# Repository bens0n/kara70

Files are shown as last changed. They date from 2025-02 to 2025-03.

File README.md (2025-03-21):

# kara70
70% FRL TKL keyboard assembled with primarily through hole components, including usb type-c. Inspired by cftkb [discipline](https://github.com/coseyfannitutti/discipline) and [mysterium](https://github.com/coseyfannitutti/mysterium), and also envious' [delirium](https://github.com/Envious-Data/Env-KB). 

kara70

kara70

The microcontroller has been updated from an atmega to an RP2040, which is mounted on the back-side to maintain the through-hole look. A slightly unnecessary logic shifter does double duty as a pretend through-hole controller. Underglow RGB has been added, and a minimal (LED diffusing) case connects the base to the plate.

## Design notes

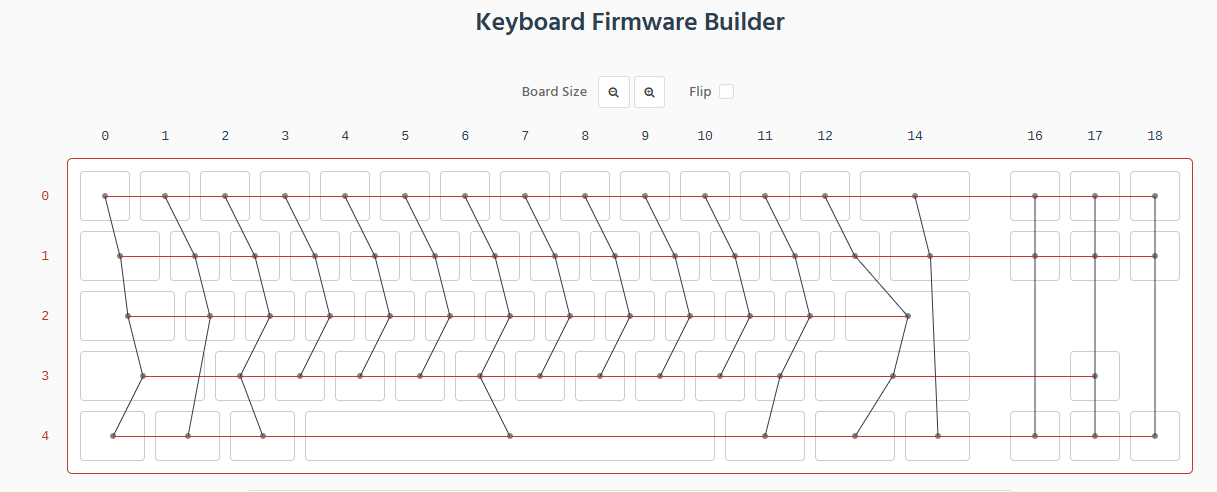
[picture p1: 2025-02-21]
keyboard-matrix.PNG

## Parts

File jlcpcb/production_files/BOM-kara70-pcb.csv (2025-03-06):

Comment | Designator | Footprint | LCSC | Quantity
100nF 0805 | C1,C10,C11,C12,C13,C14,C15,C16,C17,C18,C19,C2,C20,C21,C22,C23,C24,C3,C4,C5,C6,C7,C8,C9 | C_0805_2012Metric_Pad1.18x1.45mm_HandSolder | C28233 | 24
WS2812B | LED1,LED10,LED11,LED12,LED13,LED14,LED15,LED16,LED17,LED18,LED19,LED2,LED20,LED21,LED22,LED23,LED24,LED3,LED4,LED5,LED6,LED7,LED8,LED9 | LED_WS2812B_PLCC4_5.0x5.0mm_P3.2mm | C4154882 | 24
~ | D1 | D_DO-35_SOD27_P5.08mm_Horizontal |  | 1
~ | D2 | D_DO-35_SOD27_P5.08mm_Horizontal |  | 1
~ | D3 | D_DO-35_SOD27_P5.08mm_Horizontal |  | 1
~ | D4 | D_DO-35_SOD27_P5.08mm_Horizontal |  | 1
~ | D5 | D_DO-35_SOD27_P5.08mm_Horizontal |  | 1
~ | D6 | D_DO-35_SOD27_P5.08mm_Horizontal |  | 1
~ | D7 | D_DO-35_SOD27_P5.08mm_Horizontal |  | 1
~ | D8 | D_DO-35_SOD27_P5.08mm_Horizontal |  | 1
~ | D9 | D_DO-35_SOD27_P5.08mm_Horizontal |  | 1
~ | D10 | D_DO-35_SOD27_P5.08mm_Horizontal |  | 1
~ | D11 | D_DO-35_SOD27_P5.08mm_Horizontal |  | 1
~ | D12 | D_DO-35_SOD27_P5.08mm_Horizontal |  | 1
~ | D13 | D_DO-35_SOD27_P5.08mm_Horizontal |  | 1
~ | D14 | D_DO-35_SOD27_P5.08mm_Horizontal |  | 1
~ | D16 | D_DO-35_SOD27_P5.08mm_Horizontal |  | 1
~ | D17 | D_DO-35_SOD27_P5.08mm_Horizontal |  | 1
~ | D18 | D_DO-35_SOD27_P5.08mm_Horizontal |  | 1
~ | D19 | D_DO-35_SOD27_P5.08mm_Horizontal |  | 1
~ | D20 | D_DO-35_SOD27_P5.08mm_Horizontal |  | 1
~ | D21 | D_DO-35_SOD27_P5.08mm_Horizontal |  | 1
~ | D22 | D_DO-35_SOD27_P5.08mm_Horizontal |  | 1
~ | D23 | D_DO-35_SOD27_P5.08mm_Horizontal |  | 1
~ | D24 | D_DO-35_SOD27_P5.08mm_Horizontal |  | 1
~ | D25 | D_DO-35_SOD27_P5.08mm_Horizontal |  | 1
~ | D26 | D_DO-35_SOD27_P5.08mm_Horizontal |  | 1
~ | D27 | D_DO-35_SOD27_P5.08mm_Horizontal |  | 1
~ | D28 | D_DO-35_SOD27_P5.08mm_Horizontal |  | 1
~ | D29 | D_DO-35_SOD27_P5.08mm_Horizontal |  | 1
~ | D31 | D_DO-35_SOD27_P5.08mm_Horizontal |  | 1
~ | D32 | D_DO-35_SOD27_P5.08mm_Horizontal |  | 1
~ | D33 | D_DO-35_SOD27_P5.08mm_Horizontal |  | 1
~ | D34 | D_DO-35_SOD27_P5.08mm_Horizontal |  | 1
~ | D35 | D_DO-35_SOD27_P5.08mm_Horizontal |  | 1
~ | D36 | D_DO-35_SOD27_P5.08mm_Horizontal |  | 1
~ | D37 | D_DO-35_SOD27_P5.08mm_Horizontal |  | 1
~ | D38 | D_DO-35_SOD27_P5.08mm_Horizontal |  | 1
~ | D39 | D_DO-35_SOD27_P5.08mm_Horizontal |  | 1
~ | D40 | D_DO-35_SOD27_P5.08mm_Horizontal |  | 1
~ | D41 | D_DO-35_SOD27_P5.08mm_Horizontal |  | 1
~ | D42 | D_DO-35_SOD27_P5.08mm_Horizontal |  | 1
~ | D43 | D_DO-35_SOD27_P5.08mm_Horizontal |  | 1
~ | D45 | D_DO-35_SOD27_P5.08mm_Horizontal |  | 1
~ | D46 | D_DO-35_SOD27_P5.08mm_Horizontal |  | 1
~ | D47 | D_DO-35_SOD27_P5.08mm_Horizontal |  | 1
~ | D48 | D_DO-35_SOD27_P5.08mm_Horizontal |  | 1
~ | D49 | D_DO-35_SOD27_P5.08mm_Horizontal |  | 1
~ | D50 | D_DO-35_SOD27_P5.08mm_Horizontal |  | 1
~ | D51 | D_DO-35_SOD27_P5.08mm_Horizontal |  | 1
~ | D52 | D_DO-35_SOD27_P5.08mm_Horizontal |  | 1
~ | D53 | D_DO-35_SOD27_P5.08mm_Horizontal |  | 1
~ | D54 | D_DO-35_SOD27_P5.08mm_Horizontal |  | 1
~ | D55 | D_DO-35_SOD27_P5.08mm_Horizontal |  | 1
~ | D56 | D_DO-35_SOD27_P5.08mm_Horizontal |  | 1
~ | D59 | D_DO-35_SOD27_P5.08mm_Horizontal |  | 1
~ | D60 | D_DO-35_SOD27_P5.08mm_Horizontal |  | 1
~ | D61 | D_DO-35_SOD27_P5.08mm_Horizontal |  | 1
~ | D62 | D_DO-35_SOD27_P5.08mm_Horizontal |  | 1
~ | D73 | D_DO-35_SOD27_P5.08mm_Horizontal |  | 1
~ | D74 | D_DO-35_SOD27_P5.08mm_Horizontal |  | 1
~ | D79 | D_DO-35_SOD27_P5.08mm_Horizontal |  | 1
SN74AHCT125N | U1 | N14 |  | 1
~ | D75 | D_DO-35_SOD27_P5.08mm_Horizontal |  | 1
3.6V | D70 | D_DO-35_SOD27_P5.08mm_Horizontal |  | 1
USB_C_GCT_USB4085 | USB1 | USB_C_GCT_USB4085 |  | 1
5.1k | R2 | R_Axial_DIN0204_L3.6mm_D1.6mm_P7.62mm_Horizontal |  | 1
~ | D81 | D_DO-35_SOD27_P5.08mm_Horizontal |  | 1
~ | D83 | D_DO-35_SOD27_P5.08mm_Horizontal |  | 1
~ | D57 | D_DO-35_SOD27_P5.08mm_Horizontal |  | 1
~ | D82 | D_DO-35_SOD27_P5.08mm_Horizontal |  | 1
5.1k | R1 | R_Axial_DIN0204_L3.6mm_D1.6mm_P7.62mm_Horizontal |  | 1
~ | D76 | D_DO-35_SOD27_P5.08mm_Horizontal |  | 1
~ | D77 | D_DO-35_SOD27_P5.08mm_Horizontal |  | 1
500mA | F1 | polyfuse_5.1mm |  | 1
~ | D72 | D_DO-35_SOD27_P5.08mm_Horizontal |  | 1
3.6V | D69 | D_DO-35_SOD27_P5.08mm_Horizontal |  | 1
~ | D78 | D_DO-35_SOD27_P5.08mm_Horizontal |  | 1
~ | D80 | D_DO-35_SOD27_P5.08mm_Horizontal |  | 1
KEYSW | SW1 | MX-Hotswap-1U |  | 1
KEYSW | SW2 | MX-Hotswap-1U |  | 1
KEYSW | SW3 | MX-Hotswap-1U |  | 1
KEYSW | SW4 | MX-Hotswap-1U |  | 1
KEYSW | SW5 | MX-Hotswap-1U |  | 1
KEYSW | SW6 | MX-Hotswap-1U |  | 1
KEYSW | SW7 | MX-Hotswap-1U |  | 1
KEYSW | SW8 | MX-Hotswap-1U |  | 1
KEYSW | SW9 | MX-Hotswap-1U |  | 1
KEYSW | SW10 | MX-Hotswap-1U |  | 1
KEYSW | SW11 | MX-Hotswap-1U |  | 1
KEYSW | SW12 | MX-Hotswap-1U |  | 1
KEYSW | SW13 | MX-Hotswap-1U |  | 1
KEYSW | SW17 | MX-Hotswap-1U |  | 1
KEYSW | SW18 | MX-Hotswap-1U |  | 1
KEYSW | SW19 | MX-Hotswap-1U |  | 1
KEYSW | SW20 | MX-Hotswap-1U |  | 1
KEYSW | SW21 | MX-Hotswap-1U |  | 1
KEYSW | SW22 | MX-Hotswap-1U |  | 1
KEYSW | SW23 | MX-Hotswap-1U |  | 1
KEYSW | SW24 | MX-Hotswap-1U |  | 1
KEYSW | SW25 | MX-Hotswap-1U |  | 1
KEYSW | SW26 | MX-Hotswap-1U |  | 1
KEYSW | SW27 | MX-Hotswap-1U |  | 1
KEYSW | SW28 | MX-Hotswap-1U |  | 1
KEYSW | SW32 | MX-Hotswap-1U |  | 1
KEYSW | SW33 | MX-Hotswap-1U |  | 1
KEYSW | SW34 | MX-Hotswap-1U |  | 1
KEYSW | SW35 | MX-Hotswap-1U |  | 1
KEYSW | SW36 | MX-Hotswap-1U |  | 1
KEYSW | SW37 | MX-Hotswap-1U |  | 1
KEYSW | SW38 | MX-Hotswap-1U |  | 1
KEYSW | SW39 | MX-Hotswap-1U |  | 1
KEYSW | SW40 | MX-Hotswap-1U |  | 1
KEYSW | SW41 | MX-Hotswap-1U |  | 1
KEYSW | SW42 | MX-Hotswap-1U |  | 1
KEYSW | SW46 | MX-Hotswap-1U |  | 1
KEYSW | SW47 | MX-Hotswap-1U |  | 1
KEYSW | SW48 | MX-Hotswap-1U |  | 1
KEYSW | SW49 | MX-Hotswap-1U |  | 1
KEYSW | SW50 | MX-Hotswap-1U |  | 1
KEYSW | SW51 | MX-Hotswap-1U |  | 1
KEYSW | SW52 | MX-Hotswap-1U |  | 1
KEYSW | SW53 | MX-Hotswap-1U |  | 1
KEYSW | SW54 | MX-Hotswap-1U |  | 1
KEYSW | SW55 | MX-Hotswap-1U |  | 1
KEYSW | SW62 | MX-Hotswap-7U-ReversedStabilizers |  | 1
KEYSW | SW14 | MX-Hotswap-2U |  | 1
KEYSW | SW29 | MX-Hotswap-1.5U |  | 1
KEYSW | SW31 | MX-Hotswap-1.75U |  | 1
KEYSW | SW43 | MX-Hotswap-2.25U |  | 1
KEYSW | SW45 | MX-Hotswap-2.25U |  | 1
KEYSW | SW56 | MX-Hotswap-2.75U |  | 1
KEYSW | SW59 | MX-Hotswap-1.25U |  | 1
KEYSW | SW60 | MX-Hotswap-1.25U |  | 1
KEYSW | SW61 | MX-Hotswap-1.25U |  | 1
KEYSW | SW73 | MX-Hotswap-1.5U |  | 1
KEYSW | SW74 | MX-Hotswap-1.5U |  | 1
KEYSW | SW16 | MX-Hotswap-1.5U |  | 1
KEYSW | SW82 | MX-Hotswap-1U |  | 1
KEYSW | SW80 | MX-Hotswap-1U |  | 1
KEYSW | SW83 | MX-Hotswap-1U |  | 1
KEYSW | SW81 | MX-Hotswap-1U |  | 1
KEYSW | SW76 | MX-Hotswap-1U |  | 1
KEYSW | SW72 | MX-Hotswap-1U |  | 1
KEYSW | SW79 | MX-Hotswap-1U |  | 1
KEYSW | SW77 | MX-Hotswap-1U |  | 1
KEYSW | SW57 | MX-Hotswap-1.25U |  | 1
KEYSW | SW78 | MX-Hotswap-1U |  | 1
KEYSW | SW75 | MX-Hotswap-1U |  | 1
RP2040_Stamp | U2 | RP2xxx_Stamp_SMD |  | 1

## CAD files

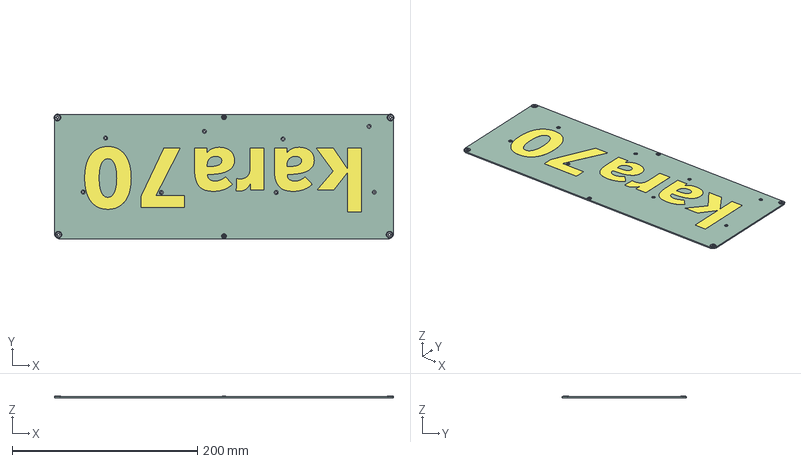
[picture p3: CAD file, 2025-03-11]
base/base.step
366.8 x 134.6 x 2.14 mm
STP_9774005360_rev1 x 4
STP_9774005243_rev1 x 2
base_copper
base_pad
base_PCB

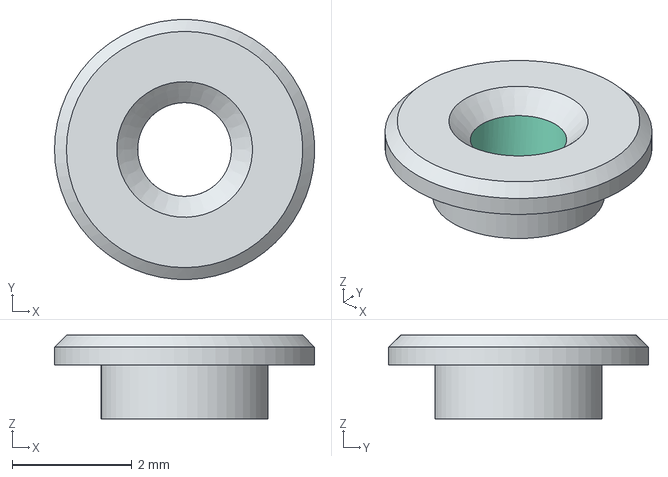
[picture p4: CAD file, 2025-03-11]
discipline-lib/3d/STP_9774005243_rev1.stp
4.35 x 4.35 x 1.40 mm

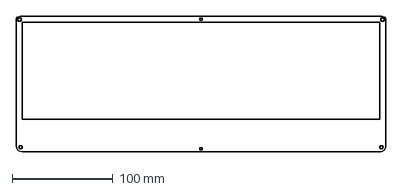
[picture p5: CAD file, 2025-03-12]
laser_cutting/acrylic_top_plate.dxf
366.2 x 134.3 mm

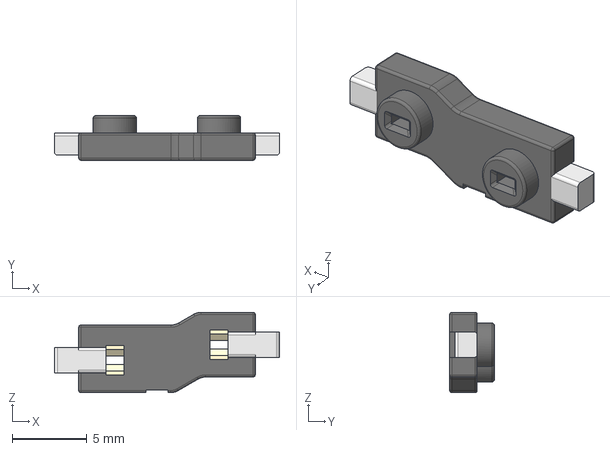
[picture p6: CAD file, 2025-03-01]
MX_V2/3D/Gateron-KS33-Socket.step
15.1 x 3.00 x 5.40 mm

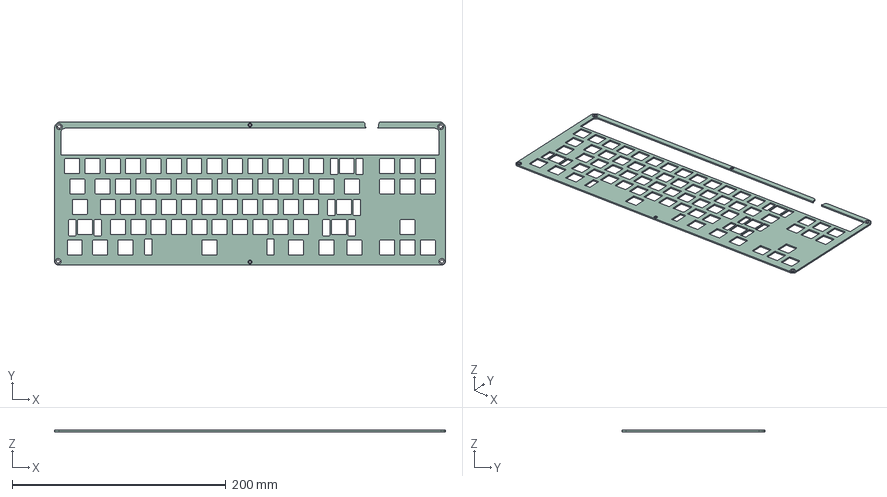
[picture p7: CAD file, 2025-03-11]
plate/plate.step
366.2 x 134.3 x 1.59 mm
plate_pad
plate_PCB

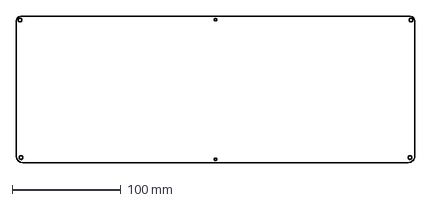
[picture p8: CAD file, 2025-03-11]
base/base-outline.dxf
366.2 x 134.3 mm

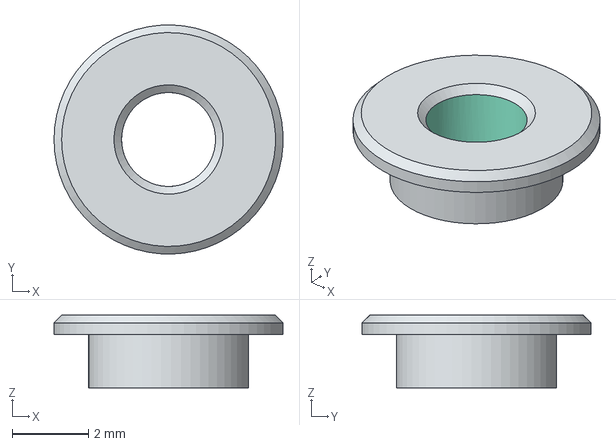
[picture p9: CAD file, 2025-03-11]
discipline-lib/3d/STP_9774005360_rev1.stp
6.00 x 6.00 x 1.90 mm

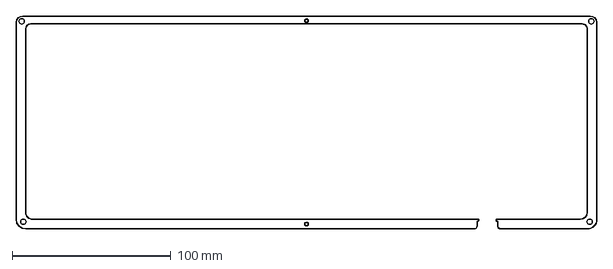
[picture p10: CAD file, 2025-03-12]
laser_cutting/diffuser_with_cutout.dxf
366.2 x 134.3 mm

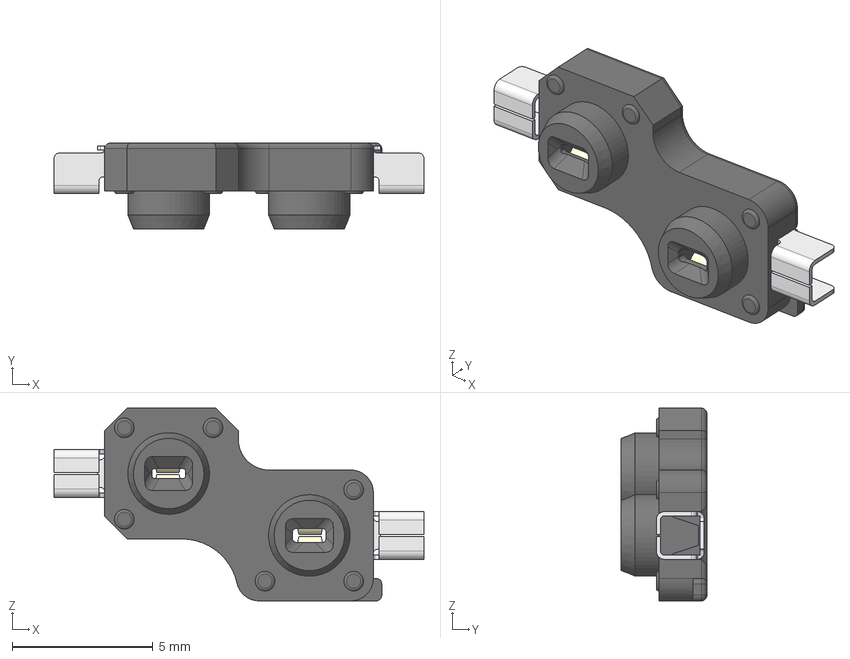
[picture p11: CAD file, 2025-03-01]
MX_V2/3D/Kailh-Choc-Socket-CPG135001S30.step
13.1 x 3.05 x 6.85 mm
Insert 2
Insert 1

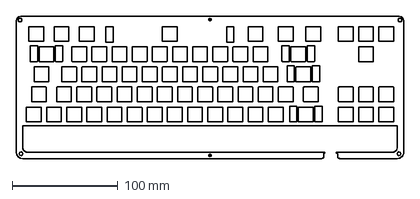
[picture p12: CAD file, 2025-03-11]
plate/plate-outline.dxf
366.2 x 134.3 mm

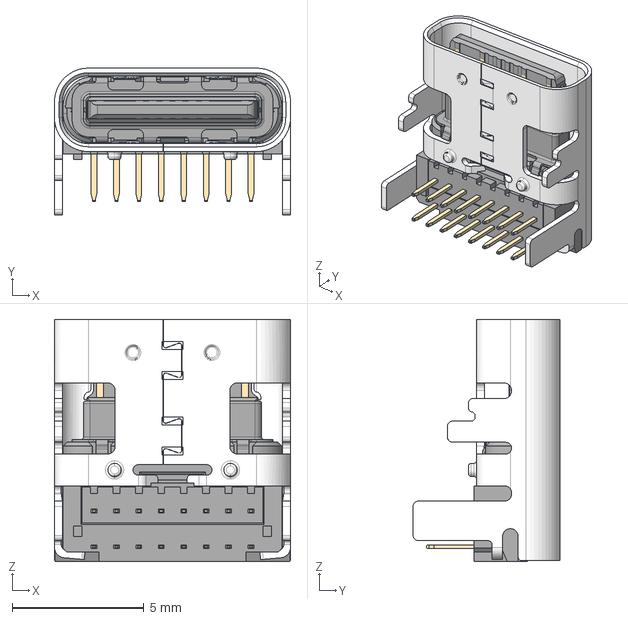
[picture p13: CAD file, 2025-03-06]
discipline-lib/3d/usb4085-gf-a.stp
8.94 x 5.56 x 9.17 mm

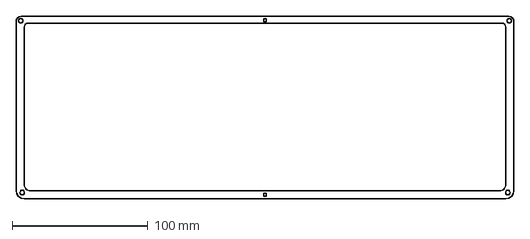
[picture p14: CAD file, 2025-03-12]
laser_cutting/diffuser_no_cutout.dxf
366.2 x 134.3 mm

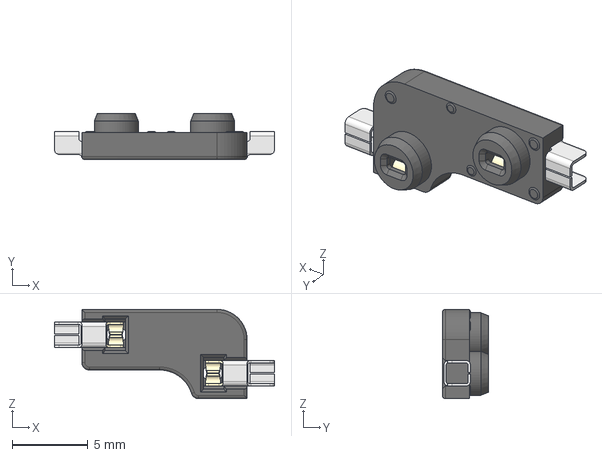
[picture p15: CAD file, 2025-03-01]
MX_V2/3D/MX-Hotswap-Socket.step
14.5 x 3.05 x 5.89 mm

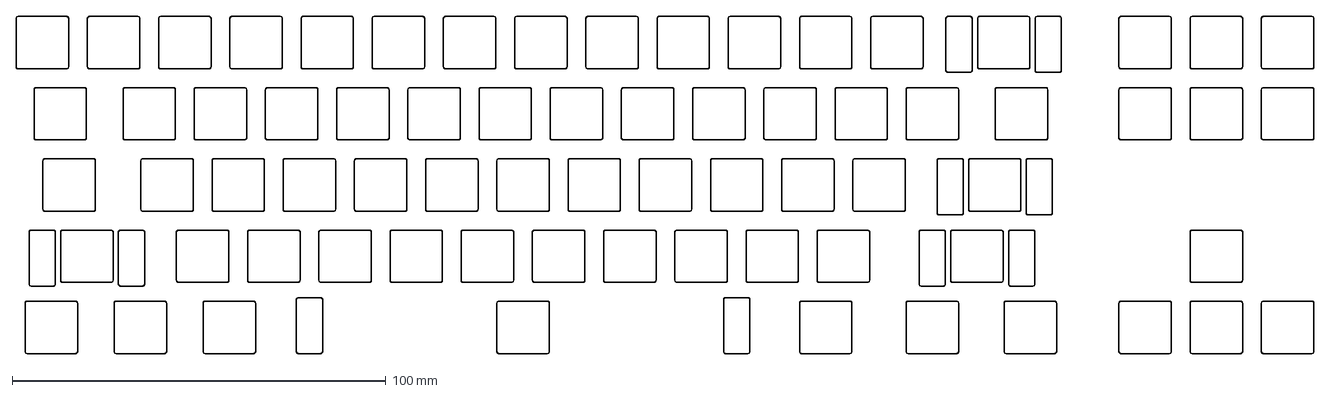
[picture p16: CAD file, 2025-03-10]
plate/keebio_plate_gen.dxf
347.1 x 90.2 mm

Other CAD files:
plate/pcb_outline.dxf
plate/ai03_plate_gen.dxf
discipline-lib/3d/usb4085-gf-a.stl

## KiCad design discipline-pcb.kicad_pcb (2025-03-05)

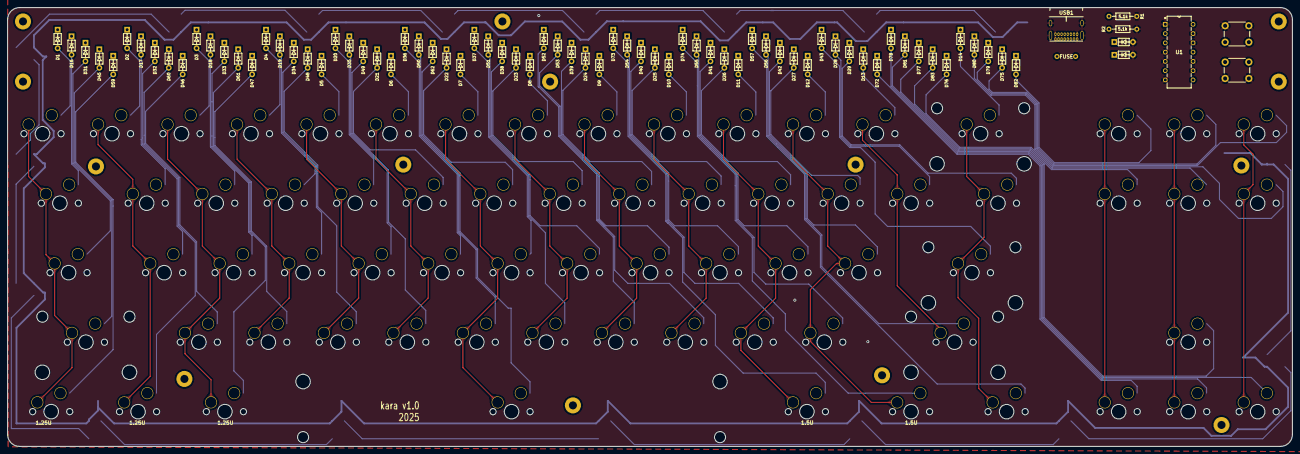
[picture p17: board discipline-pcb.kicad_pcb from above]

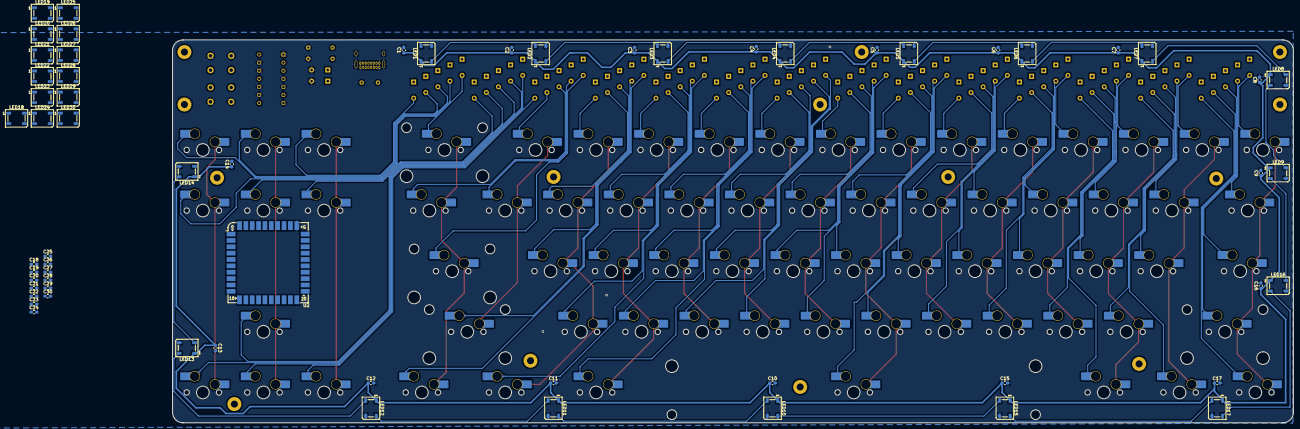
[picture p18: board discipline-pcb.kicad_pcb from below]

Board: 2 copper layers, 352.2 x 120.3 mm, 210 parts (131 on the bottom side), 132 nets.

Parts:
C1, C2, C3, C4, C5, C6, C7, C8, C9, C10, C11, C12, C13, C14, C15, C16, C17, C18, C19, C20, C21, C22, C23, C24, C25, C26, C27, C28, C29, C30: 100nF 0603; C_0603_1608Metric_Pad1.08x0.95mm_HandSolder
D1, D2, D3, D4, D5, D6, D7, D8, D9, D10, D11, D12, D13, D14, D16, D17, D18, D19, D20, D21, D22, D23, D24, D25, D26, D27, D28, D29, D31, D32, D33, D34, D35, D36, D37, D38, D39, D40, D41, D42, D43, D45, D46, D47, D48, D49, D50, D51, D52, D53, D54, D55, D56, D57, D59, D60, D61, D62, D72, D73, D74, D75, D76, D77, D78, D79, D80, D81, D82, D83: D_DO-35_SOD27_P5.08mm_Horizontal
D69, D70: 3.6V; D_DO-35_SOD27_P5.08mm_Horizontal
F1: 500mA; polyfuse_5.1mm
LED1, LED2, LED3, LED4, LED5, LED6, LED7, LED8, LED9, LED10, LED11, LED12, LED13, LED14, LED15, LED16, LED17, LED18, LED19, LED20, LED21, LED22, LED23, LED24, LED25, LED26, LED27, LED28, LED29, LED30: WS2812B; LED_WS2812B_PLCC4_5.0x5.0mm_P3.2mm
R1, R2: 5.1k; R_Axial_DIN0204_L3.6mm_D1.6mm_P7.62mm_Horizontal
SW1, SW2, SW3, SW4, SW5, SW6, SW7, SW8, SW9, SW10, SW11, SW12, SW13, SW17, SW18, SW19, SW20, SW21, SW22, SW23, SW24, SW25, SW26, SW27, SW28, SW32, SW33, SW34, SW35, SW36, SW37, SW38, SW39, SW40, SW41, SW42, SW46, SW47, SW48, SW49, SW50, SW51, SW52, SW53, SW54, SW55, SW72, SW75, SW76, SW77, SW78, SW79, SW80, SW81, SW82, SW83: KEYSW; MX-Hotswap-1U
SW14: KEYSW; MX-Hotswap-2U
SW16, SW29, SW73, SW74: KEYSW; MX-Hotswap-1.5U
SW31: KEYSW; MX-Hotswap-1.75U
SW43, SW45: KEYSW; MX-Hotswap-2.25U
SW56: KEYSW; MX-Hotswap-2.75U
SW57, SW59, SW60, SW61: KEYSW; MX-Hotswap-1.25U
SW62: KEYSW; MX-Hotswap-7U-ReversedStabilizers
SW-RST1, SW-RST2: SW_PUSH_6mm
U1: SN74AHCT125N; N14
U2: RP2040_Stamp; RP2xxx_Stamp_SMD
USB1: USB_C_GCT_USB4085

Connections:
+5V: C1.1, C2.1, C3.1, C4.1, C5.1, C6.1, C7.1, C8.1, C9.1, C10.1, C11.1, C12.1, C13.1, C14.1, C15.1, C16.1, C17.1, C18.1, C19.1, C20.1, C21.1, C22.1, C23.1, C24.1, C25.1, C26.1, C27.1, C28.1, C29.1, C30.1, F1.1, LED1.1 (VDD), LED2.1 (VDD), LED3.1 (VDD), LED4.1 (VDD), LED5.1 (VDD), LED6.1 (VDD), LED7.1 (VDD), LED8.1 (VDD), LED9.1 (VDD), LED10.1 (VDD), LED11.1 (VDD), LED12.1 (VDD), LED13.1 (VDD), LED14.1 (VDD), LED15.1 (VDD), LED16.1 (VDD), LED17.1 (VDD), LED18.1 (VDD), LED19.1 (VDD), LED20.1 (VDD), LED21.1 (VDD), LED22.1 (VDD), LED23.1 (VDD), LED24.1 (VDD), LED25.1 (VDD), LED26.1 (VDD), LED27.1 (VDD), LED28.1 (VDD), LED29.1 (VDD), LED30.1 (VDD), U1.14 (VCC), U2.33 (5V)
Bootselbtn: SW-RST2.1, U2.40 (BOOTSEL)
D+: D70.1 (K), U2.36 (USB_D+), USB1.A6 (DP1), USB1.B6 (DP2)
D-: D69.1 (K), U2.35 (USB_D-), USB1.A7 (DN1), USB1.B7 (DN2)
GND: C1.2, C2.2, C3.2, C4.2, C5.2, C6.2, C7.2, C8.2, C9.2, C10.2, C11.2, C12.2, C13.2, C14.2, C15.2, C16.2, C17.2, C18.2, C19.2, C20.2, C21.2, C22.2, C23.2, C24.2, C25.2, C26.2, C27.2, C28.2, C29.2, C30.2, D69.2 (A), D70.2 (A), LED1.3 (VSS), LED2.3 (VSS), LED3.3 (VSS), LED4.3 (VSS), LED5.3 (VSS), LED6.3 (VSS), LED7.3 (VSS), LED8.3 (VSS), LED9.3 (VSS), LED10.3 (VSS), LED11.3 (VSS), LED12.3 (VSS), LED13.3 (VSS), LED14.3 (VSS), LED15.3 (VSS), LED16.3 (VSS), LED17.3 (VSS), LED18.3 (VSS), LED19.3 (VSS), LED20.3 (VSS), LED21.3 (VSS), LED22.3 (VSS), LED23.3 (VSS), LED24.3 (VSS), LED25.3 (VSS), LED26.3 (VSS), LED27.3 (VSS), LED28.3 (VSS), LED29.3 (VSS), LED30.3 (VSS), R1.1, R2.2, SW-RST1.2, SW-RST2.2, U1.1 (*1OE), U1.4 (*2OE), U1.5 (2A), U1.7 (GND), U1.9 (3A), U1.10 (*3OE), U1.12 (4A), U1.13 (*4OE), U2.31 (GND), USB1.A1 (GND), USB1.A12 (GND), USB1.B1 (GND), USB1.B12 (GND), USB1.S1 (SHIELD)
unnamed: D1.2 (A), SW1.2
unnamed: D2.2 (A), SW2.2
unnamed: D3.2 (A), SW3.2
unnamed: D4.2 (A), SW4.2
unnamed: D5.2 (A), SW5.2
unnamed: D6.2 (A), SW6.2
unnamed: D7.2 (A), SW7.2
unnamed: D8.2 (A), SW8.2
unnamed: D9.2 (A), SW9.2
unnamed: D10.2 (A), SW10.2
unnamed: D11.2 (A), SW11.2
unnamed: D12.2 (A), SW12.2
unnamed: D13.2 (A), SW13.2
unnamed: D14.2 (A), SW14.2
unnamed: D16.2 (A), SW16.2
unnamed: D17.2 (A), SW17.2
unnamed: D18.2 (A), SW18.2
unnamed: D19.2 (A), SW19.2
unnamed: D20.2 (A), SW20.2
unnamed: D21.2 (A), SW21.2
unnamed: D22.2 (A), SW22.2
unnamed: D23.2 (A), SW23.2
unnamed: D24.2 (A), SW24.2
unnamed: D25.2 (A), SW25.2
unnamed: D26.2 (A), SW26.2
unnamed: D27.2 (A), SW27.2
unnamed: D28.2 (A), SW28.2
unnamed: D29.2 (A), SW29.2
unnamed: D31.2 (A), SW31.2
unnamed: D32.2 (A), SW32.2
unnamed: D33.2 (A), SW33.2
unnamed: D34.2 (A), SW34.2
unnamed: D35.2 (A), SW35.2
unnamed: D36.2 (A), SW36.2
unnamed: D37.2 (A), SW37.2
unnamed: D38.2 (A), SW38.2
unnamed: D39.2 (A), SW39.2
unnamed: D40.2 (A), SW40.2
unnamed: D41.2 (A), SW41.2
unnamed: D42.2 (A), SW42.2
unnamed: D43.2 (A), SW43.2
unnamed: D45.2 (A), SW45.2
unnamed: D46.2 (A), SW46.2
unnamed: D47.2 (A), SW47.2
unnamed: D48.2 (A), SW48.2
unnamed: D49.2 (A), SW49.2
unnamed: D50.2 (A), SW50.2
unnamed: D51.2 (A), SW51.2
unnamed: D52.2 (A), SW52.2
unnamed: D53.2 (A), SW53.2
unnamed: D54.2 (A), SW54.2
unnamed: D55.2 (A), SW55.2
unnamed: D56.2 (A), SW56.2
unnamed: D57.2 (A), SW57.2
unnamed: D59.2 (A), SW59.2
unnamed: D60.2 (A), SW60.2
unnamed: D61.2 (A), SW61.2
unnamed: D62.2 (A), SW62.2
unnamed: D72.2 (A), SW72.2
unnamed: D73.2 (A), SW73.2
unnamed: D74.2 (A), SW74.2
unnamed: D75.2 (A), SW75.2
unnamed: D76.2 (A), SW76.2
unnamed: D77.2 (A), SW77.2
unnamed: D78.2 (A), SW78.2
unnamed: D79.2 (A), SW79.2
unnamed: D80.2 (A), SW80.2
unnamed: D81.2 (A), SW81.2
unnamed: D82.2 (A), SW82.2
unnamed: D83.2 (A), SW83.2
unnamed: LED1.2 (DOUT), LED2.4 (DIN)
unnamed: LED2.2 (DOUT), LED3.4 (DIN)
unnamed: LED3.2 (DOUT), LED4.4 (DIN)
unnamed: LED4.2 (DOUT), LED5.4 (DIN)
unnamed: LED5.2 (DOUT), LED6.4 (DIN)
unnamed: LED6.2 (DOUT), LED7.4 (DIN)
unnamed: LED7.2 (DOUT), LED8.4 (DIN)
unnamed: LED8.2 (DOUT), LED9.4 (DIN)
unnamed: LED9.2 (DOUT), LED10.4 (DIN)
unnamed: LED10.2 (DOUT), LED11.4 (DIN)
unnamed: LED11.2 (DOUT), LED12.4 (DIN)
unnamed: LED12.2 (DOUT), LED13.4 (DIN)
unnamed: LED13.2 (DOUT), LED14.4 (DIN)
unnamed: LED14.2 (DOUT), LED15.4 (DIN)
unnamed: LED15.2 (DOUT), LED16.4 (DIN)
unnamed: LED16.2 (DOUT), LED17.4 (DIN)
unnamed: LED17.2 (DOUT), LED18.4 (DIN)
unnamed: LED18.2 (DOUT), LED19.4 (DIN)
unnamed: LED19.2 (DOUT), LED20.4 (DIN)
unnamed: LED20.2 (DOUT), LED21.4 (DIN)
unnamed: LED21.2 (DOUT), LED22.4 (DIN)
unnamed: LED22.2 (DOUT), LED23.4 (DIN)
unnamed: LED23.2 (DOUT), LED24.4 (DIN)
unnamed: LED24.2 (DOUT), LED25.4 (DIN)
unnamed: LED25.2 (DOUT), LED26.4 (DIN)
unnamed: LED26.2 (DOUT), LED27.4 (DIN)
unnamed: LED27.2 (DOUT), LED28.4 (DIN)
unnamed: LED28.2 (DOUT), LED29.4 (DIN)
unnamed: LED29.2 (DOUT), LED30.4 (DIN)
unnamed: R1.2, USB1.A5 (CC1)
unnamed: R2.1, USB1.B5 (CC2)
Resetbtn: SW-RST1.1, U2.39 (~RESET)
VCC: F1.2, USB1.A4 (VBUS), USB1.A9 (VBUS), USB1.B4 (VBUS), USB1.B9 (VBUS)
col0: SW1.1, SW16.1, SW31.1, SW45.1, SW59.1, U2.16 (GPIO15)
col1: SW2.1, SW17.1, SW32.1, SW60.1, U2.15 (GPIO14)
col2: SW3.1, SW18.1, SW33.1, SW46.1, SW61.1, U2.14 (GPIO13)
col3: SW4.1, SW19.1, SW34.1, SW47.1, U2.13 (GPIO12)
col4: SW5.1, SW20.1, SW35.1, SW48.1, U2.12 (GPIO11)
col5: SW6.1, SW21.1, SW36.1, SW49.1, U2.11 (GPIO10)
col6: SW7.1, SW22.1, SW37.1, SW50.1, SW62.1, U2.10 (GPIO9)
col7: SW8.1, SW23.1, SW38.1, SW51.1, U2.9 (GPIO8)
col8: SW9.1, SW24.1, SW39.1, SW52.1, U2.8 (GPIO7)
col9: SW10.1, SW25.1, SW40.1, SW53.1, U2.7 (GPIO6)
col10: SW11.1, SW26.1, SW41.1, SW54.1, SW73.1, U2.6 (GPIO5)
col11: SW12.1, SW27.1, SW42.1, SW55.1, SW74.1, U2.5 (GPIO4)
col12: SW13.1, SW28.1, SW56.1, U2.4 (GPIO3)
col13: SW14.1, SW29.1, SW43.1, SW57.1, U2.17 (GPIO16)
col14: SW72.1, SW82.1, SW83.1, U2.3 (GPIO2)
col15: SW75.1, SW76.1, SW77.1, SW78.1, U2.2 (GPIO1)
col16: SW79.1, SW80.1, SW81.1, U2.1 (GPIO0)
led5vout: LED1.4 (DIN), U1.3 (1Y)
ledpin: U1.2 (1A), U2.18 (GPIO17)
row0: D1.1 (K), D2.1 (K), D3.1 (K), D4.1 (K), D5.1 (K), D6.1 (K), D7.1 (K), D8.1 (K), D9.1 (K), D10.1 (K), D11.1 (K), D12.1 (K), D13.1 (K), D14.1 (K), D75.1 (K), D79.1 (K), D82.1 (K), U2.22 (GPIO21)
row1: D16.1 (K), D17.1 (K), D18.1 (K), D19.1 (K), D20.1 (K), D21.1 (K), D22.1 (K), D23.1 (K), D24.1 (K), D25.1 (K), D26.1 (K), D27.1 (K), D28.1 (K), D29.1 (K), D76.1 (K), D80.1 (K), D83.1 (K), U2.21 (GPIO20)
row2: D31.1 (K), D32.1 (K), D33.1 (K), D34.1 (K), D35.1 (K), D36.1 (K), D37.1 (K), D38.1 (K), D39.1 (K), D40.1 (K), D41.1 (K), D42.1 (K), D43.1 (K), U2.19 (GPIO18)
row3: D45.1 (K), D46.1 (K), D47.1 (K), D48.1 (K), D49.1 (K), D50.1 (K), D51.1 (K), D52.1 (K), D53.1 (K), D54.1 (K), D55.1 (K), D56.1 (K), D77.1 (K), U2.23 (GPIO22)
row4: D57.1 (K), D59.1 (K), D60.1 (K), D61.1 (K), D62.1 (K), D72.1 (K), D73.1 (K), D74.1 (K), D78.1 (K), D81.1 (K), U2.20 (GPIO19)

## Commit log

2025-02-21 initial upgrade to kicad 8
2025-02-24 add a controller
    [discipline-pcb.kicad_pcb, discipline-pcb.kicad_sch]
2025-02-24 continue to plat
    [discipline-pcb.kicad_pcb]
2025-02-24 use sensible matrix
    [discipline-pcb.kicad_pcb, discipline-pcb.kicad_sch]
2025-02-24 more jazz
    [discipline-pcb.kicad_pcb]
2025-02-24 soldermask color
    [discipline-pcb.kicad_pcb]
2025-02-24 more routing
    [discipline-pcb.kicad_pcb]
2025-02-24 sort spacings and fix
    [discipline-pcb.kicad_pcb, discipline-pcb.kicad_sch]
2025-02-25 add stabs, update footprint for cpico
    [discipline-pcb.kicad_pcb, discipline-pcb.kicad_sch]
2025-02-25 before changing to top-strip
    [discipline-pcb.kicad_pcb]
2025-02-25 significant improvements to placement
    [discipline-pcb.kicad_pcb, discipline-pcb.kicad_sch]
2025-02-25 gross layout looking better
    [discipline-pcb.kicad_pcb, discipline-pcb.kicad_sch]
2025-02-25 starting to look like something
    [discipline-pcb.kicad_pcb, discipline-pcb.kicad_sch]
2025-02-26 add continuation marks aping diodes
    [discipline-pcb.kicad_pcb]
2025-02-26 update nets
    [discipline-pcb.kicad_pcb, discipline-pcb.kicad_sch]
2025-02-26 add dru
    [discipline-pcb.kicad_pcb, discipline-pcb.kicad_sch]
2025-02-26 update dru
    [discipline-pcb.kicad_pcb]
2025-02-26 UPDATE KARA
    [discipline-pcb.kicad_pcb]
2025-02-26 add mounting points
    [discipline-pcb.kicad_pcb]
2025-03-01 unsure - potentially revert?
    [discipline-pcb.kicad_pcb]
2025-03-01 update to hotswap; needs rerouting
    [Gateron-KS33-Socket.step, Kailh-Choc-Socket-CPG135001S30.step, MX-Hotswap-Socket.step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]
2025-03-02 add level shifter for a laugh
    [discipline-pcb.kicad_sch]
2025-03-02 add decoupling caps
    [discipline-pcb.kicad_sch]
2025-03-02 update led labels
    [discipline-pcb.kicad_sch]
2025-03-02 add leds to pcb
    [discipline-pcb.kicad_pcb, discipline-pcb.kicad_sch]
2025-03-03 add 3d model to level shifter
    [discipline-pcb.kicad_pcb, discipline-pcb.kicad_sch]
2025-03-03 move some leds
    [discipline-pcb.kicad_pcb]
2025-03-03 who knows
    [discipline-pcb.kicad_pcb]
2025-03-03 place some nets; perhaps screw up the nets
    [discipline-pcb.kicad_pcb]
2025-03-04 update footprints for solder+hotswap
    [discipline-pcb.kicad_pcb]
2025-03-04 before routing LEDs
    [discipline-pcb.kicad_pcb]
2025-03-04 rotate led footprints
    [discipline-pcb.kicad_pcb]
2025-03-04 basic LED routing
    [discipline-pcb.kicad_pcb]
2025-03-04 at point of q's
    [discipline-pcb.kicad_pcb, discipline-pcb.kicad_sch]
2025-03-05 move controller
    [discipline-pcb.kicad_pcb]
2025-03-05 after advice on usb implementation
    [discipline-pcb.kicad_pcb, discipline-pcb.kicad_sch]
2025-03-05 remove redundant resistors
    [discipline-pcb.kicad_pcb]
2025-03-05 continue routing and adding LEDs
    [discipline-pcb.kicad_pcb, discipline-pcb.kicad_sch]
2025-03-05 more led routing
2025-03-05 leds placed, diodes and MCU left...
    [discipline-pcb.kicad_sch]
2025-03-06 move to 0805
    [discipline-pcb-B_Cu.gbl, discipline-pcb-B_Mask.gbs, discipline-pcb-B_Paste.gbp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]
2025-03-06 move origin to top-left switch for easy comparison
2025-03-06 tiny tweaks [17um] to position of a couple of switches
2025-03-06 test jlcpcb export plugin
    [CPL-discipline-pcb.csv, discipline-pcb-CuBottom.gbr, discipline-pcb-CuTop.gbr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]
2025-03-06 add jlcpcb part mapping
    [BOM-discipline-pcb.csv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]
2025-03-10 cad files
    [ai03_plate_gen.dxf, pcb_outline.dxf]
2025-03-10 update kle
    [keebio_plate_gen.dxf]
2025-03-11 export additional step file and remove old files
    [discipline-bottom.dxf, discipline-closed-layer.dxf, discipline-foot-1.dxf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]
2025-03-11 very simple base implementation
    [STP_9774005243_rev1.stp, STP_9774005360_rev1.stp, base-outline.dxf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]
2025-03-11 update naming to kara
    [discipline-pcb-B_Cu.gbl, discipline-pcb-B_Mask.gbs, discipline-pcb-B_Paste.gbp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]
2025-03-11 update base to match holes in pcb
    [BOM-base.csv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]
2025-03-11 add kicad plate
    [BOM-plate.csv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]
2025-03-11 regenerate all gerbers
    [BOM-kara70-pcb.csv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]
2025-03-11 remove outdated BOM
    [BOM-discipline-pcb.csv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]
2025-03-12 add v1 case files
    [acrylic_top_plate.dxf, diffuser_no_cutout.dxf, diffuser_with_cutout.dxf]
